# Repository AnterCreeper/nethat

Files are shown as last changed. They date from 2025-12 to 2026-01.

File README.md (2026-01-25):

# Dual Gigabit Ethernet HAT


If any questions, welcome for Issues & PRs   
如果有疑问，欢迎提交Issues或PR

**WARNING! This Project is not been fully productive tested, use at your own risk!**   
**警告！该项目未经充分的生产测试，使用需要你自己衡量**

### License

This project is licensed under the LGPL-2.1-or-later license. **DO NOT** download or clone this project until you have read and agree the LICENSE.     
该项目采用 `LGPL-2.1 以及之后版本` 授权。当你下载或克隆项目时，默认已经阅读并同意该协定。

### TODO
1. Should we add one EEPROM?

### Overview

This Project contains two `RTL8211F-CG` chips which is used to explore and demonstrate FPGA Ethernet application. This Project is compatible with [CUBE](https://github.com/AnterCreeper/CUBE) FPGA Devkit.  
该项目包含两个 `RTL8211F-CG` 芯片, 用于探索和展示基于 FPGA 的以太网应用。该项目与 [CUBE](https://github.com/AnterCreeper/CUBE) 开发工具搭配。

The PCB takes 4 layers JLC04161H-3313 Stacking, 1.6mm Thickness.
PCB 采用 4 层 JLC04161H-3313 叠层, 1.6mm 厚度。

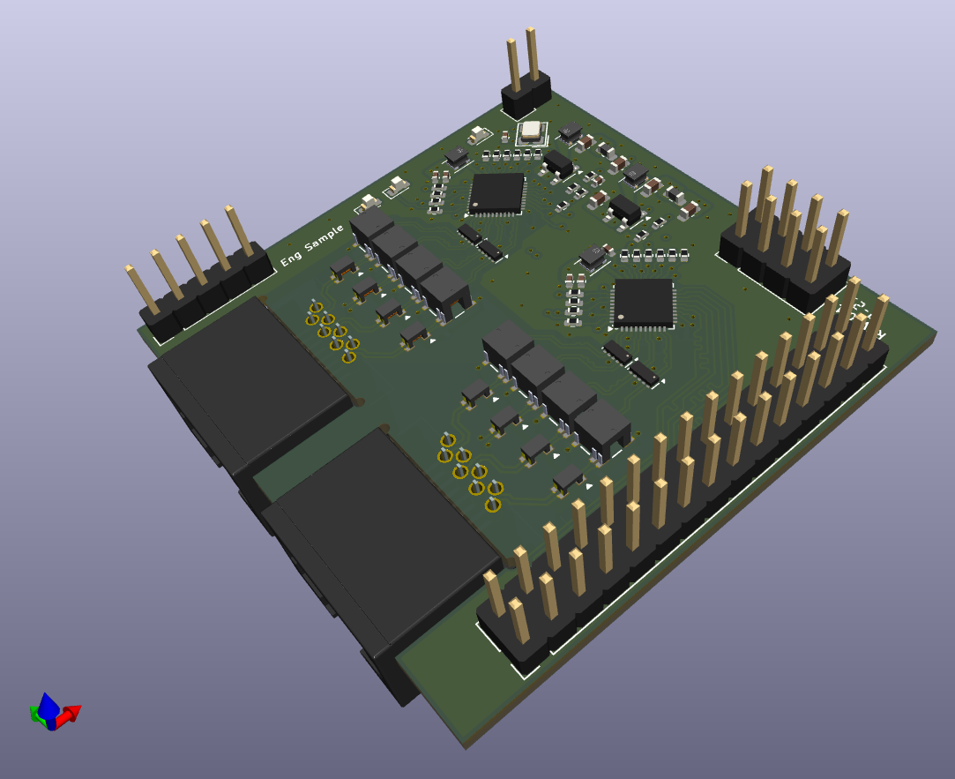
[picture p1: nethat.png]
PCB Preview Picture


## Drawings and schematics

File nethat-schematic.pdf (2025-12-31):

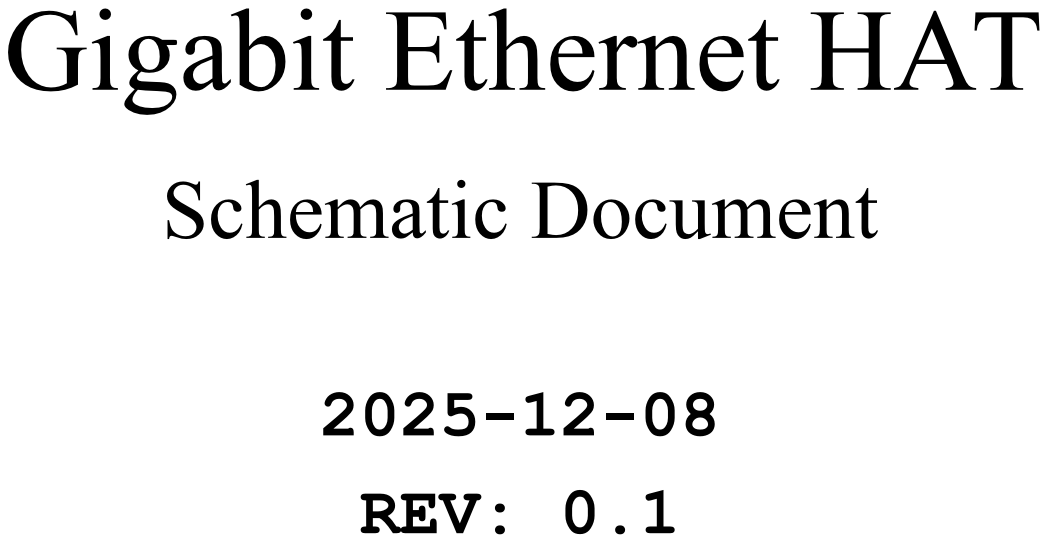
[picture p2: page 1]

Id: 1/7 Title: File: cover.kicad_sch Sheet: /COVER/ GigabitEthernetHAT
SchematicDocument

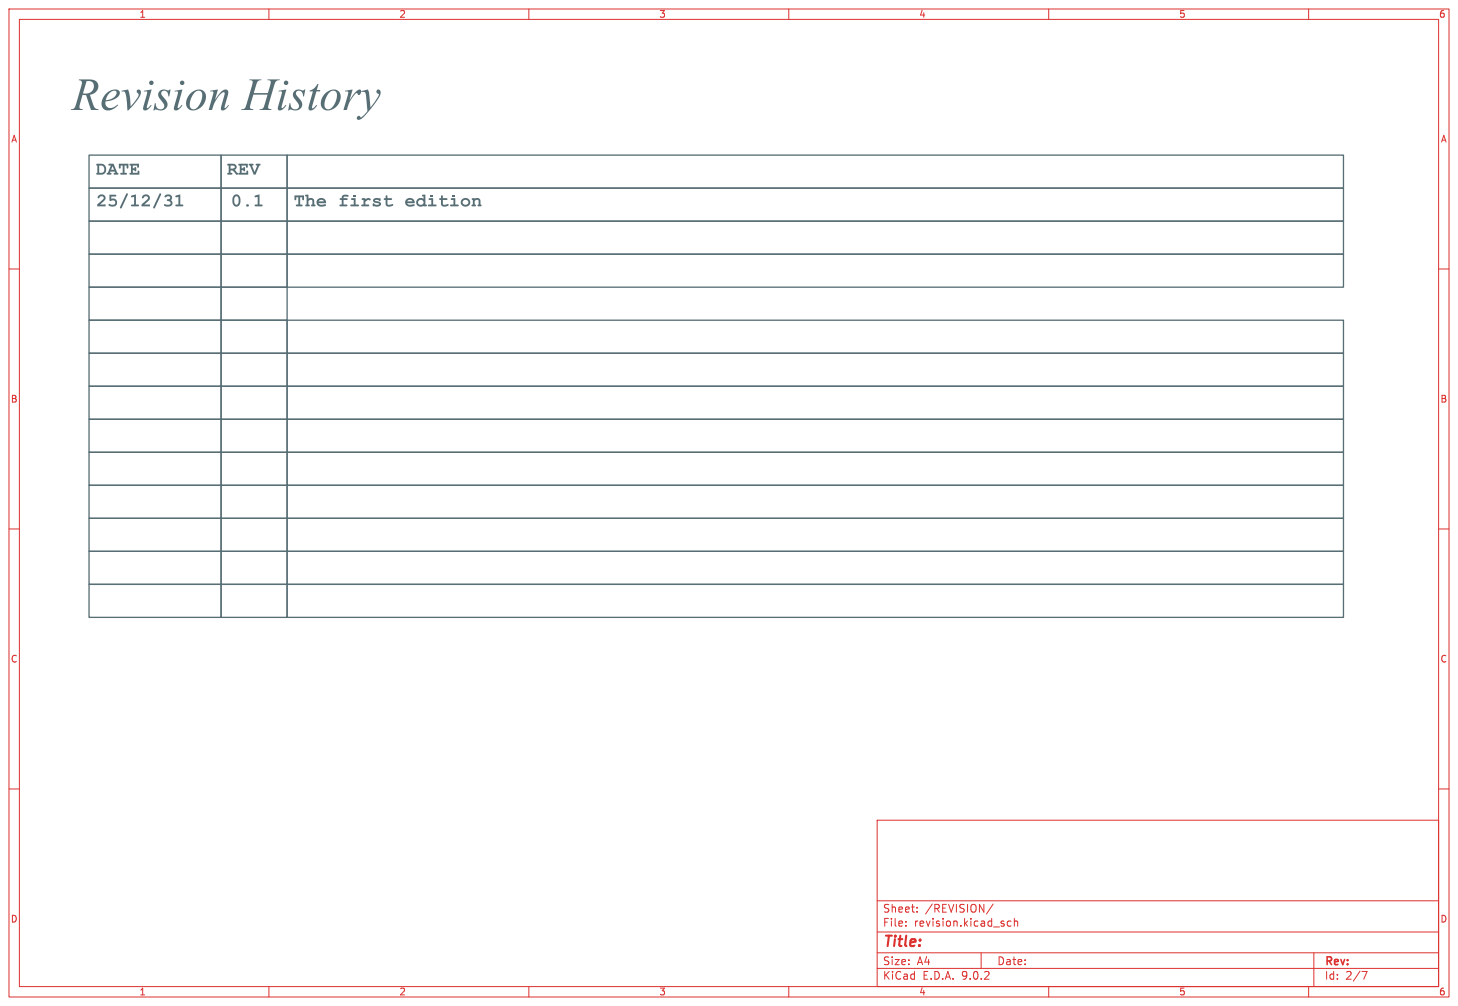
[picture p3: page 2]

Id: 2/7 Title: File: revision.kicad_sch Sheet: /REVISION/ RevisionHistory

DATE | REV
25/12/31 | 0.1 | The first edition

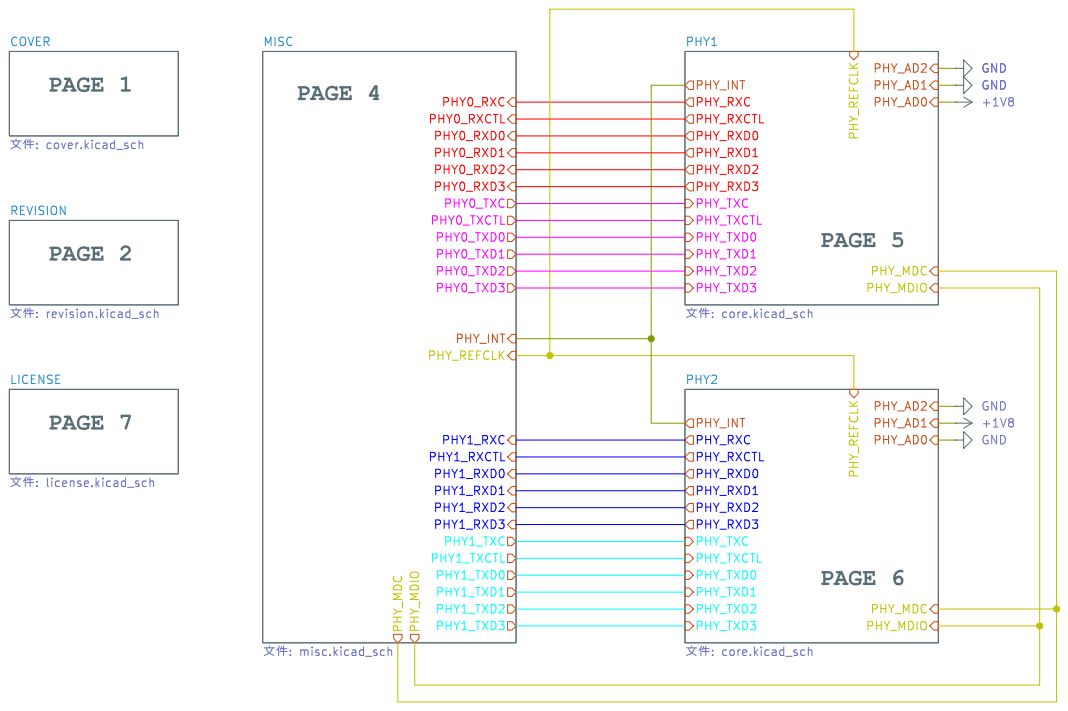
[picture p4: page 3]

þÿe‡Nö: license.kicad_sch COVER

þÿe‡Nö: cover.kicad_sch REVISION

Id: 3/7 Title: File: nethat.kicad_sch Sheet: /

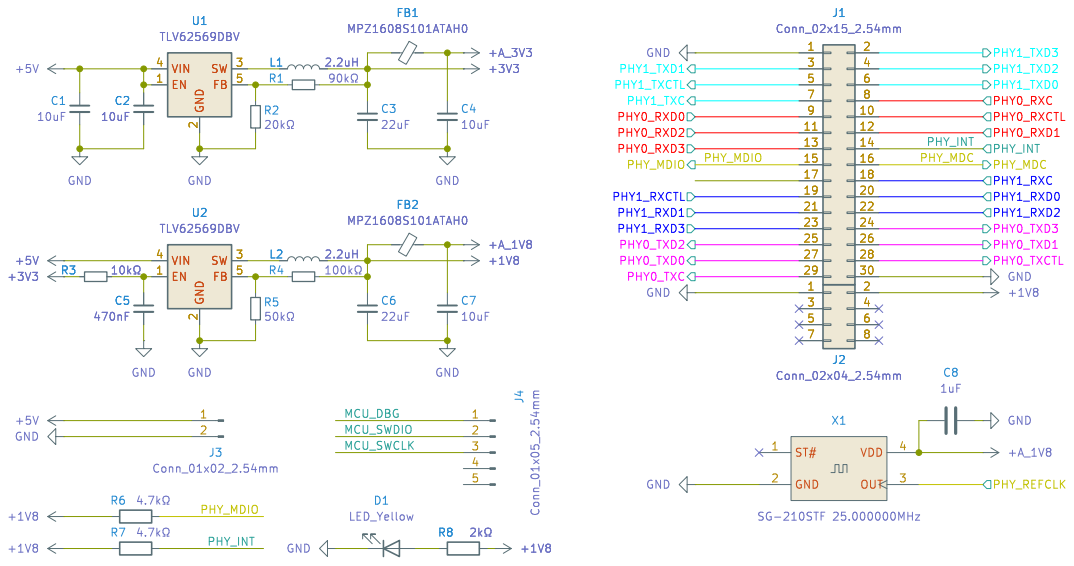
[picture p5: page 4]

2 SW 3 FB 5 U2 TLV62569DBV GND GND

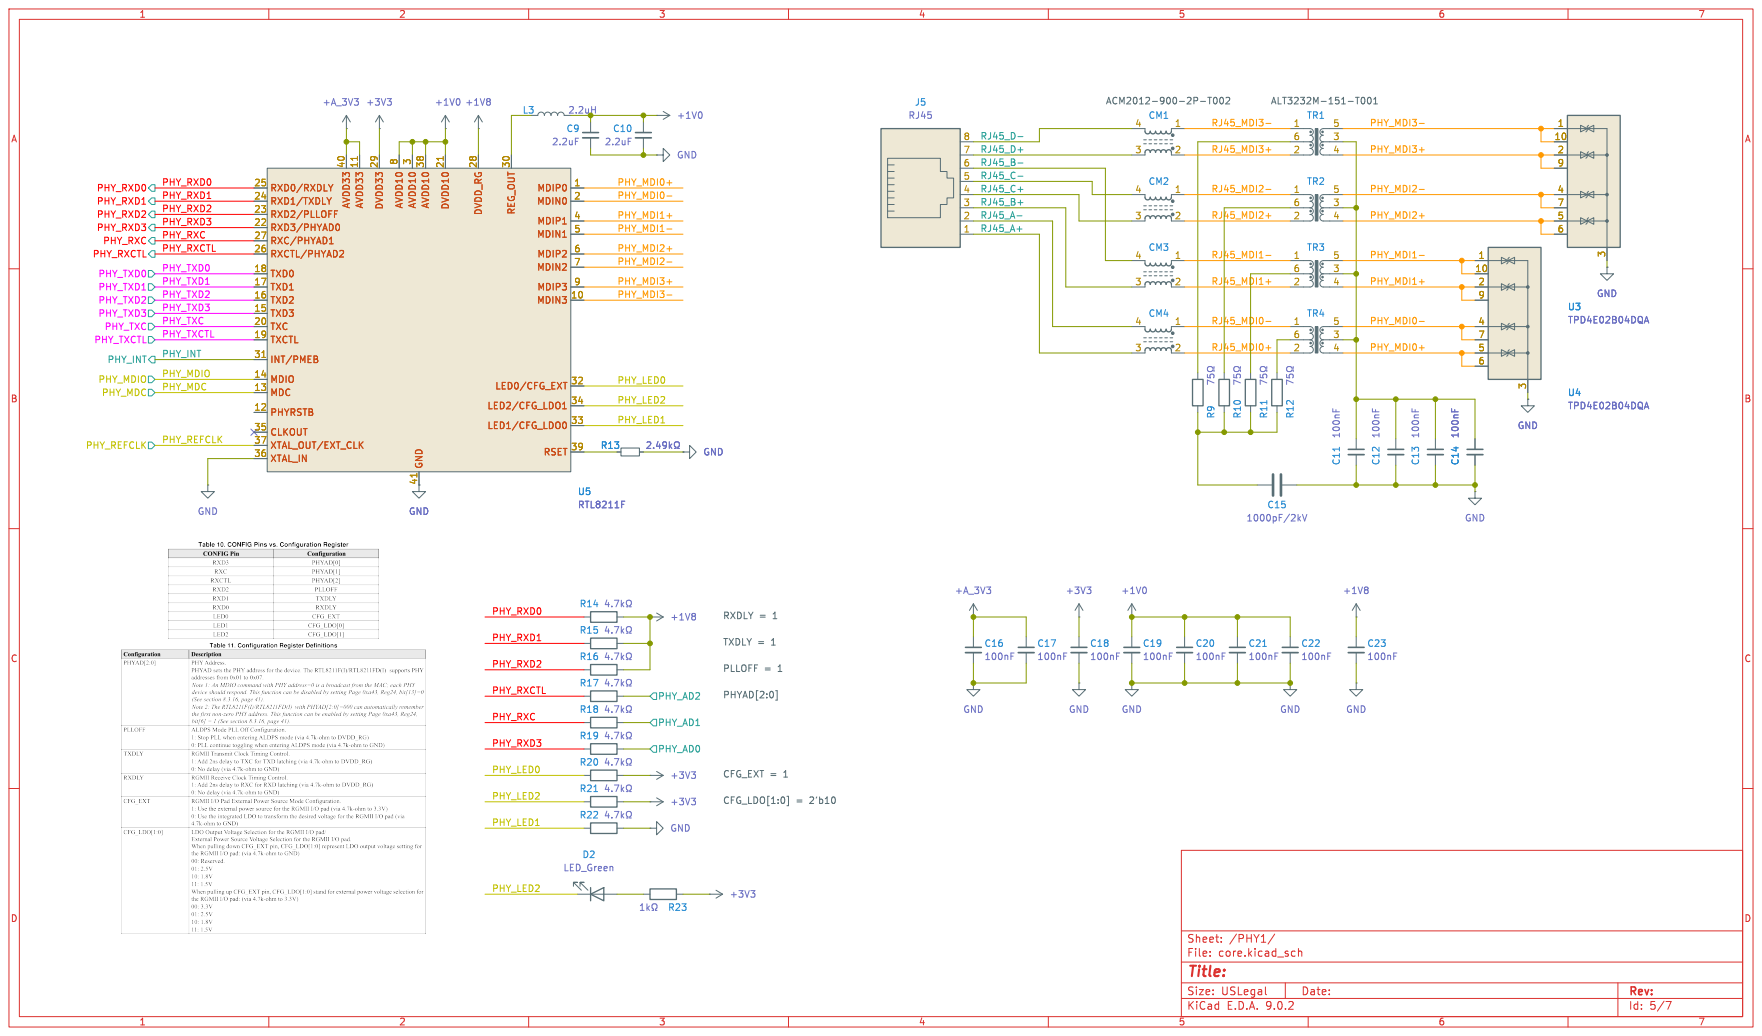
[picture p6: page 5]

Id: 5/7 Title: File: core.kicad_sch Sheet: /PHY1/

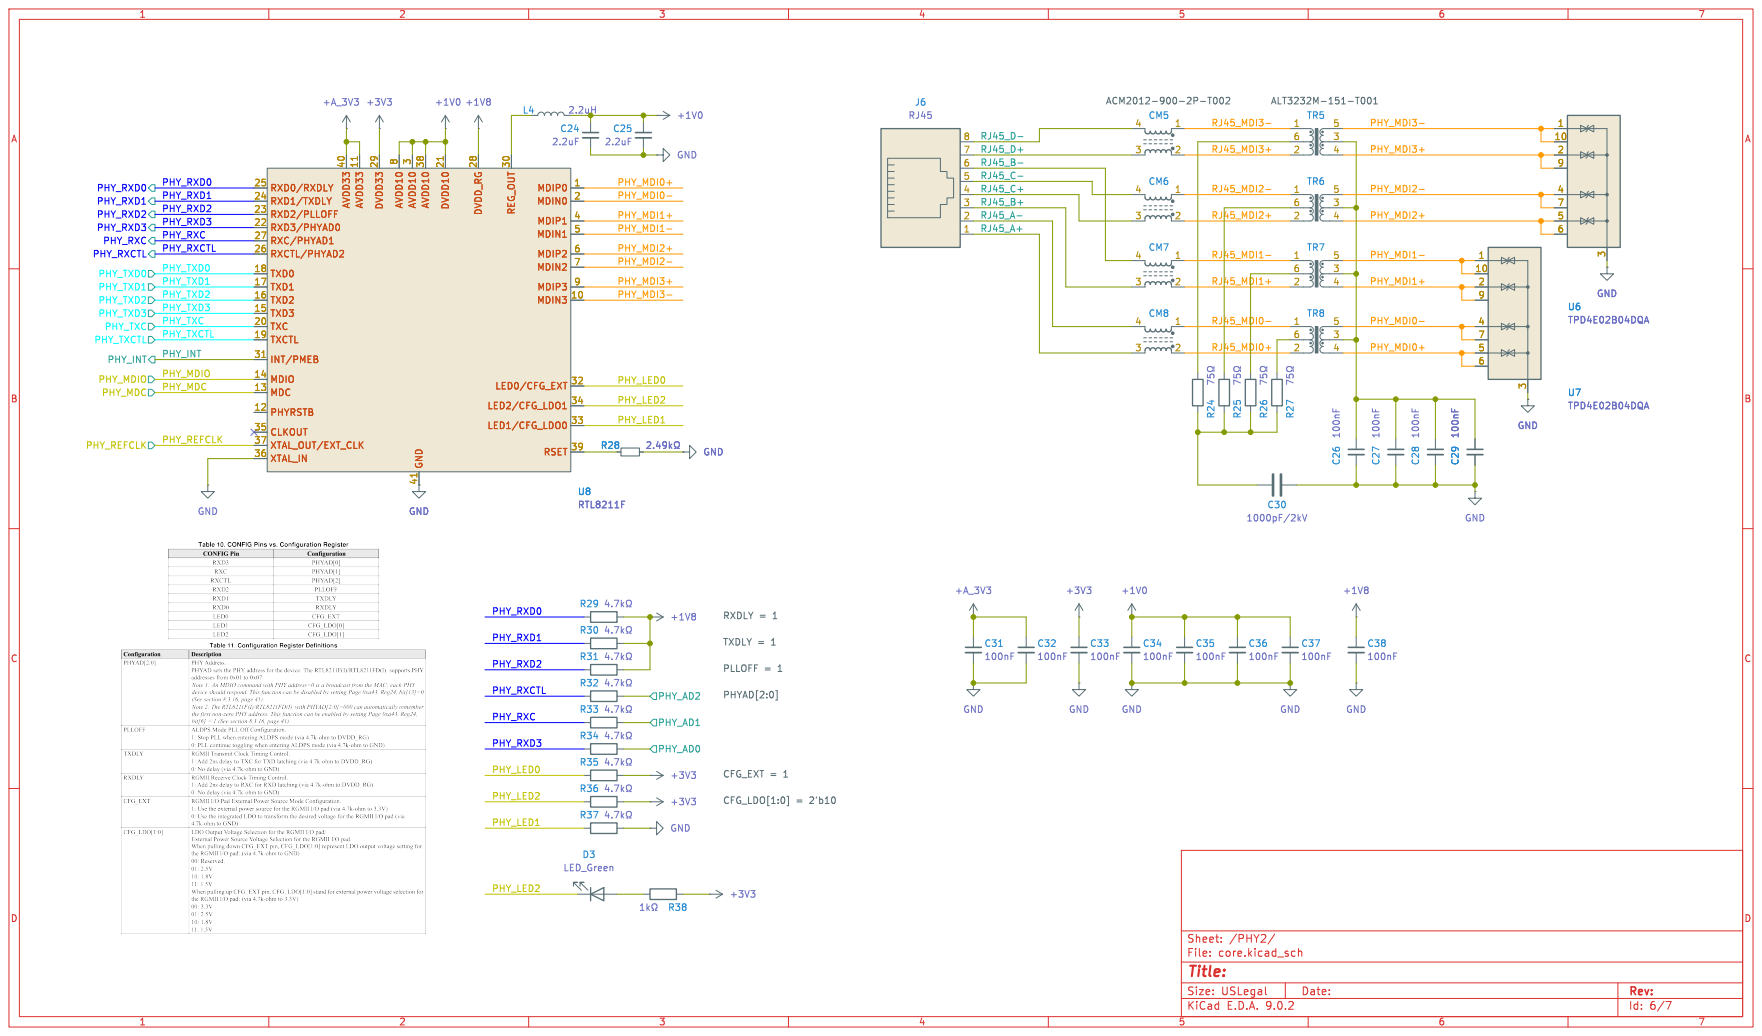
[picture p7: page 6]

Id: 6/7 Title: File: core.kicad_sch Sheet: /PHY2/

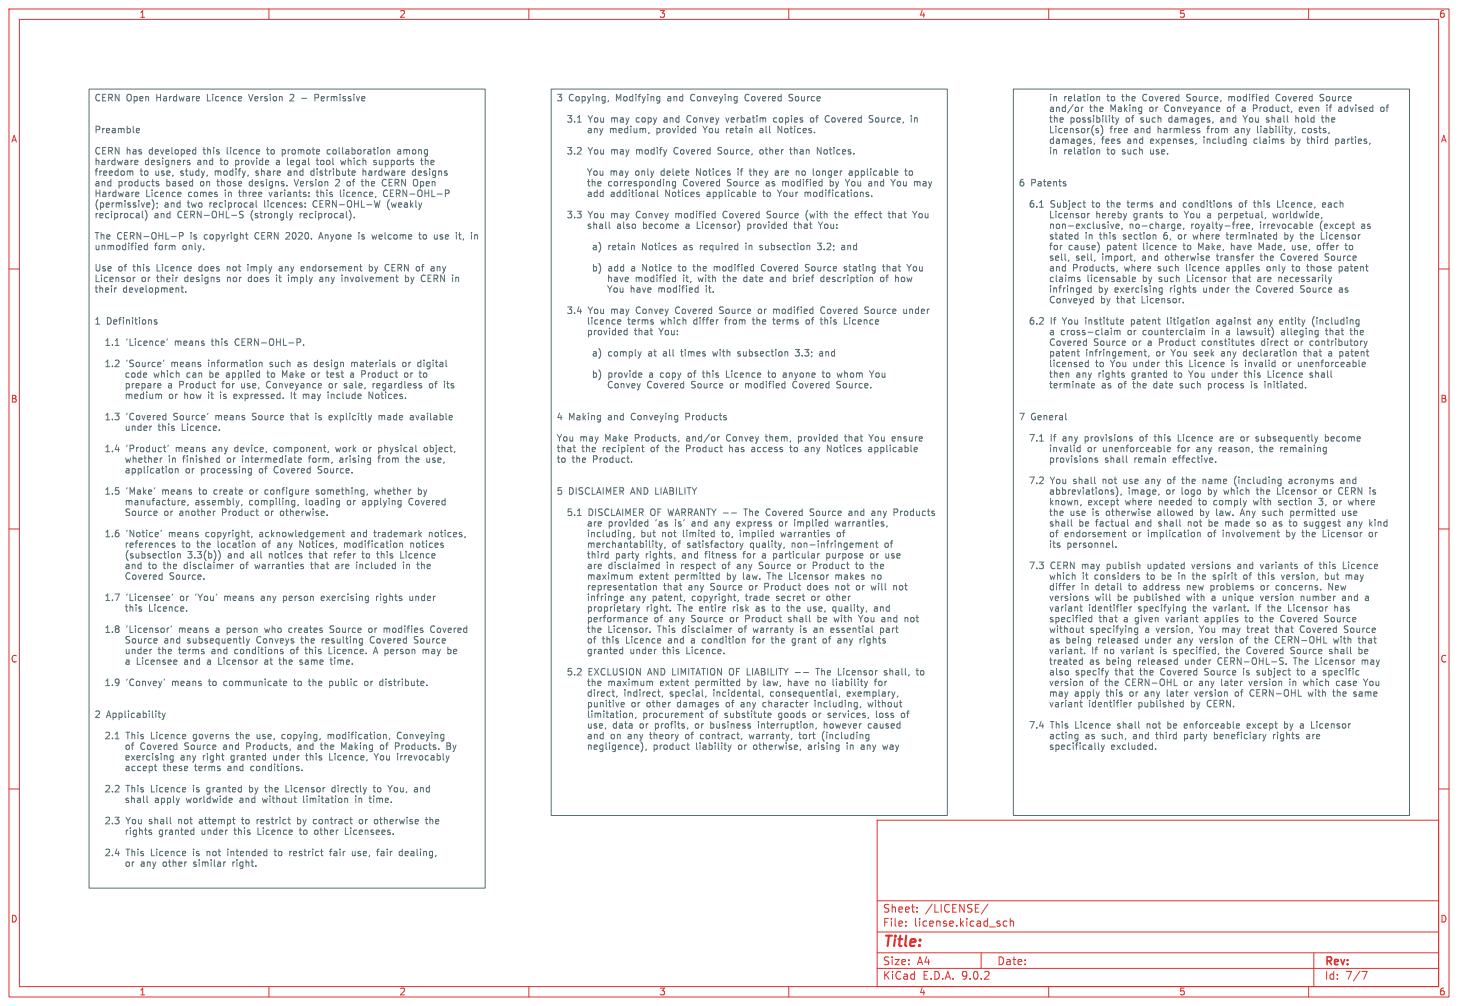
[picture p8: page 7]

for cause) patent licence to Make, have Made, use, offer to

licence terms which differ from the terms of this Licence

to the Product. 5 DISCLAIMER AND LIABILITY

known, except where needed to comply with section 3, or where

version of the CERN-OHL or any later version in which case You may apply this or any later version of CERN-OHL with the same

Id: 7/7 Title: File: license.kicad_sch Sheet: /LICENSE/

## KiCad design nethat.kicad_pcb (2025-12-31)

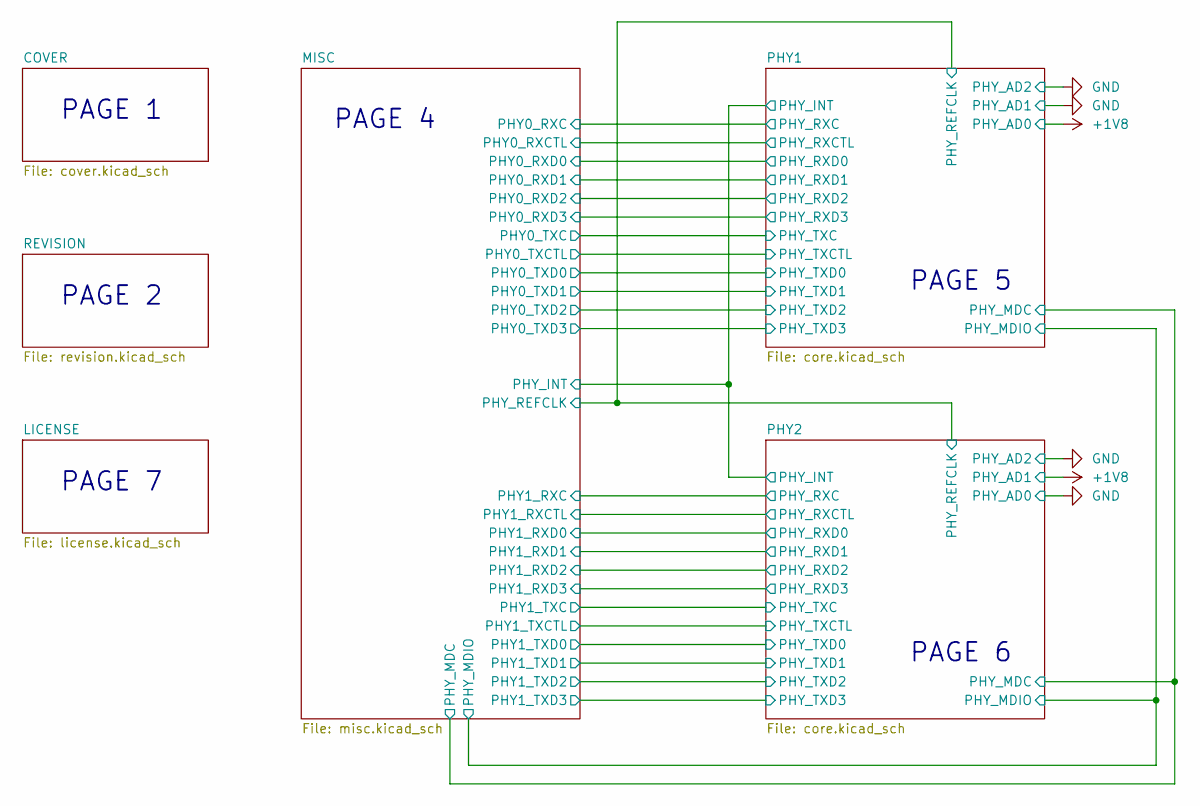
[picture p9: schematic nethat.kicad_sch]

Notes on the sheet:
PAGE 4
PAGE 1
PAGE 6
PAGE 2
PAGE 7
PAGE 5

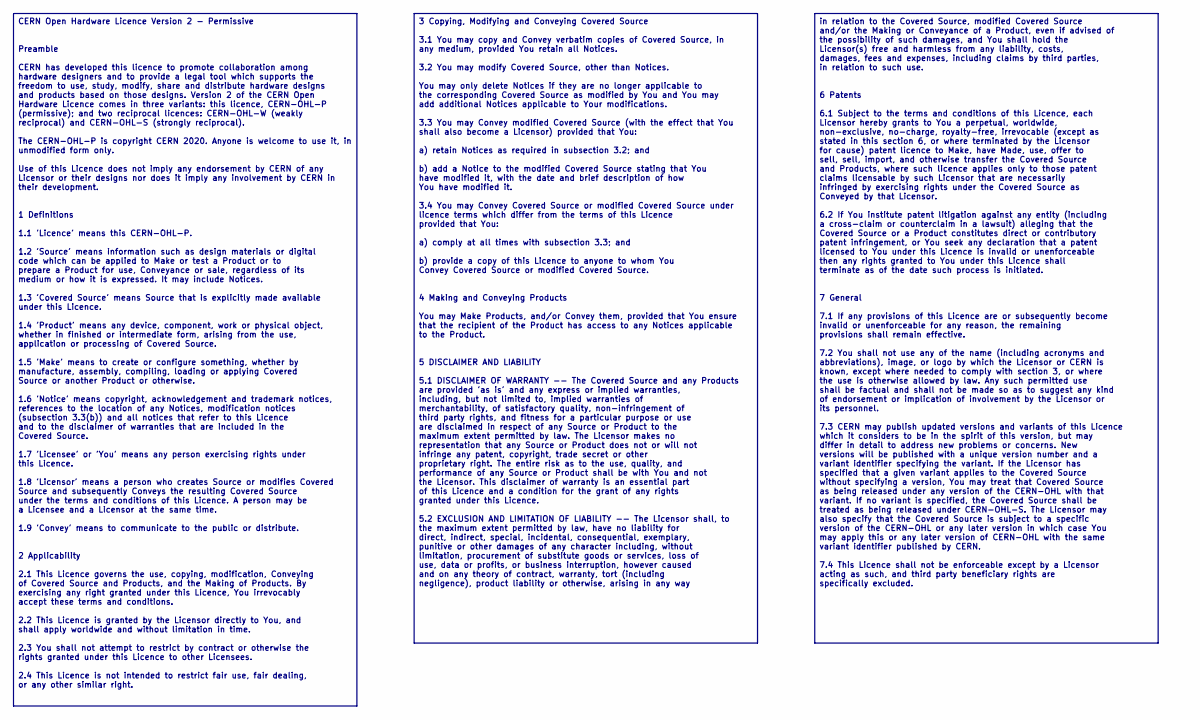
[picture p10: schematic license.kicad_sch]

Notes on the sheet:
3 Copying, Modifying and Conveying Covered Source 3.1 You may copy and Convey verbatim copies of Covered Source, in any medium, provided You retain all Notices. 3.2 You may modify Covered Source, other than Notices. You may only delete Notices if they are no longer applicable to the corresponding C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
CERN Open Hardware Licence Version 2 - Permissive Preamble CERN has developed this licence to promote collaboration among hardware designers and to provide a legal tool which supports the freedom to use, study, modify, share and distribute hardware designs and products based on those designs. Versi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
in relation to the Covered Source, modified Covered Source and/or the Making or Conveyance of a Product, even if advised of the possibility of such damages, and You shall hold the Licensor(s) free and harmless from any liability, costs, damages, fees and expenses, including claims by third parties,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

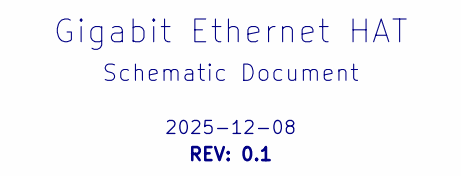
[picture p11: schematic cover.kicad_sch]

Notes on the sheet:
REV: 0.1
2025-12-08
Gigabit Ethernet HAT
Schematic Document

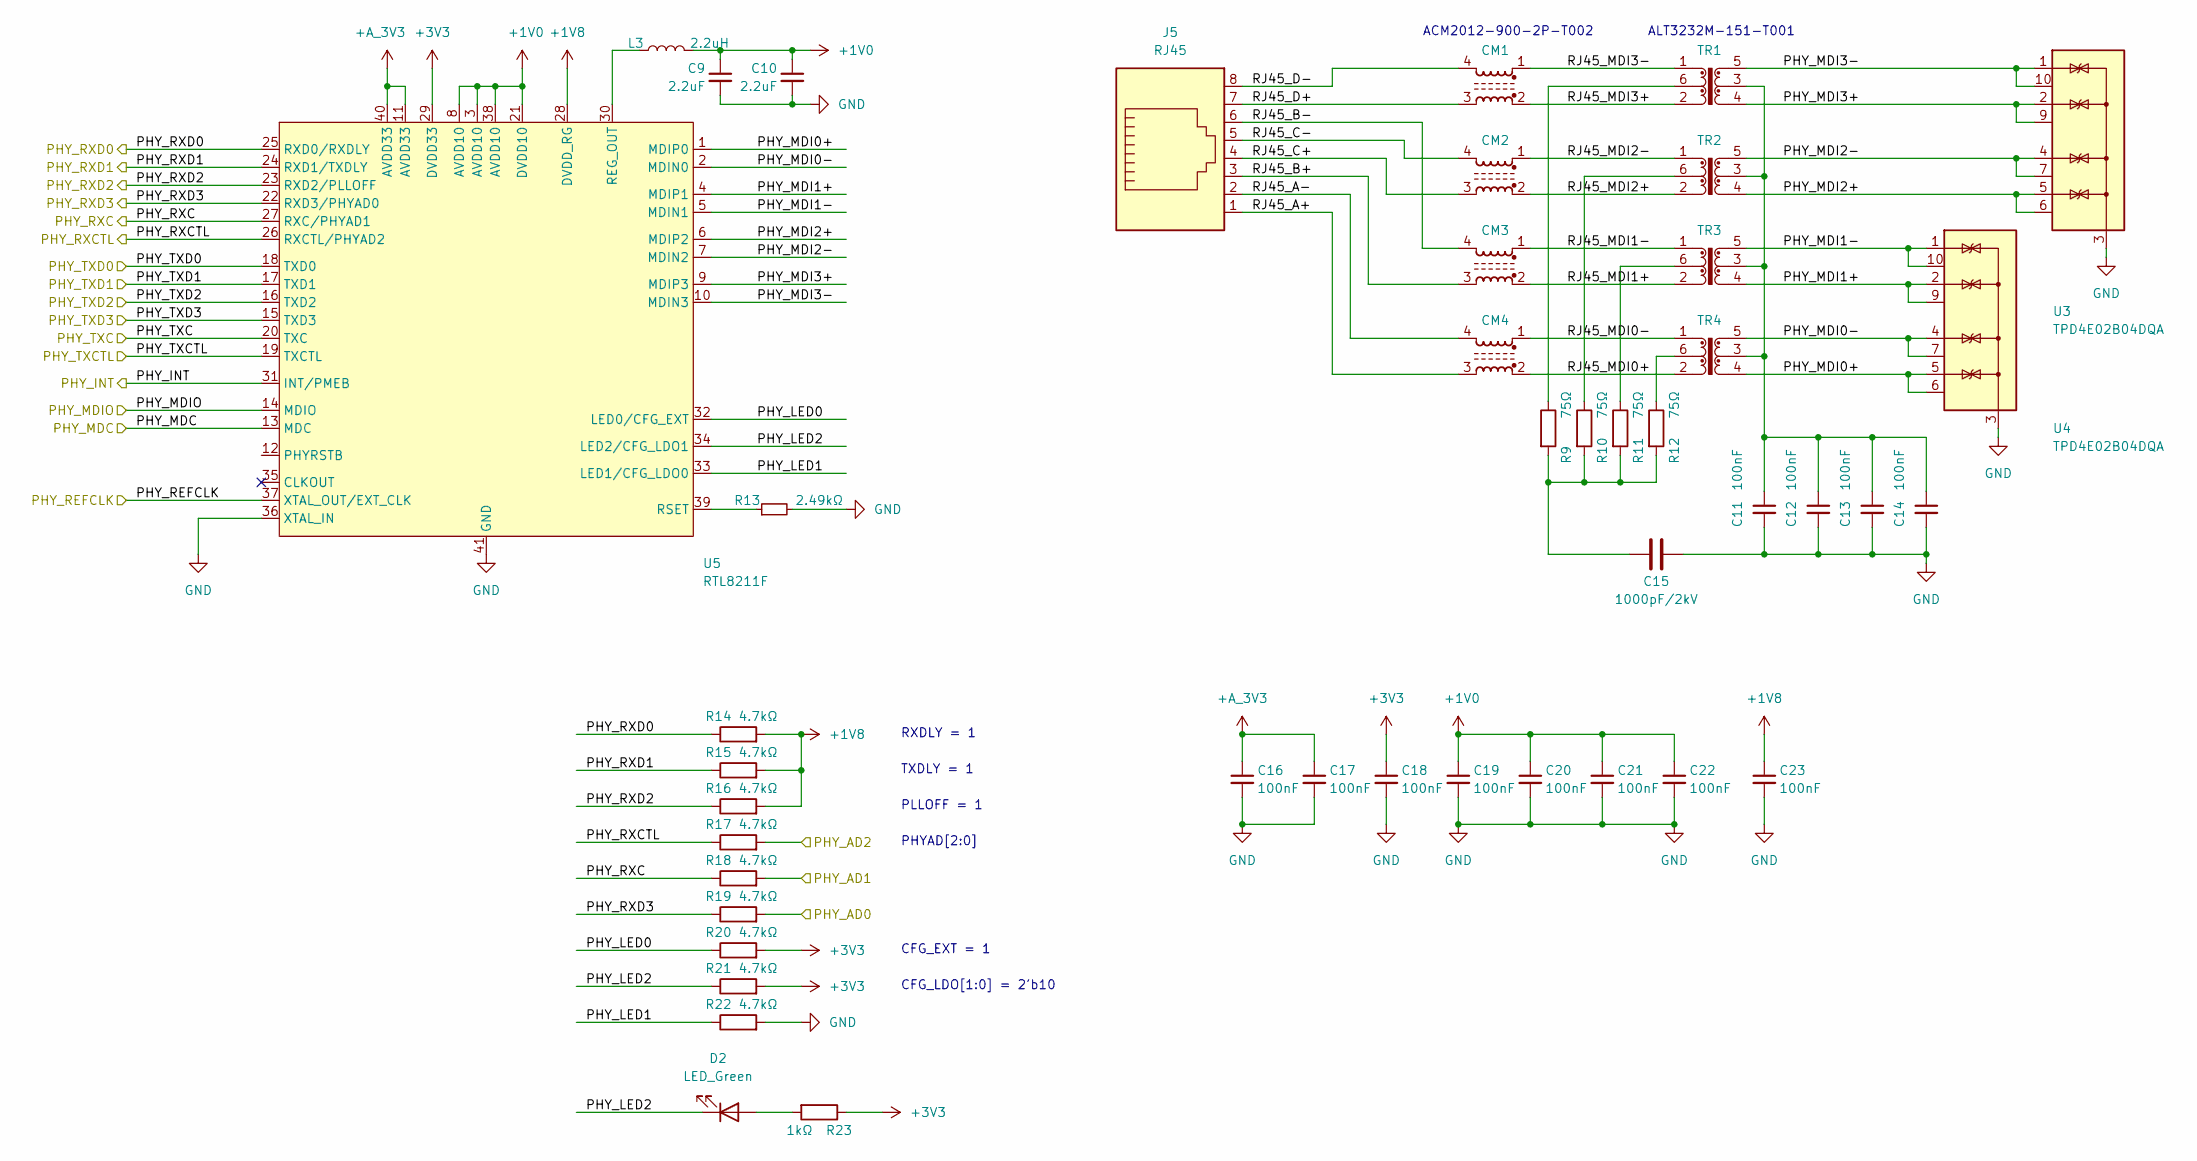
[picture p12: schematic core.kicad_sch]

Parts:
C9, C10: 2.2uF; C_0402_1005Metric
C11, C12, C13, C14, C16, C17, C18, C19, C20, C21, C22, C23: 100nF; C_0402_1005Metric
C15: 1000pF/2kV; C_1210_3225Metric
CM1, CM2, CM3, CM4: Choke_CommonMode_FerriteCore_1423; Filter_TDK_ACM2012-900-2P-T002
D2: LED_Green; LED_0603_1608Metric
J5: RJ45; RJ45_Wurth_615008150021
L3: 2.2uH; L_Murata_DFE201610P
R9, R10, R11, R12: 75Ω; R_0402_1005Metric
R13: 2.49kΩ; R_0402_1005Metric
R14, R15, R16, R17, R18, R19, R20, R21, R22: 4.7kΩ; R_0402_1005Metric
R23: 1kΩ; R_0402_1005Metric
TR1, TR2, TR3, TR4: TDK_ALT3232M_ALT4532M; Transformer_TDK_ALT3232M-151-T001
U3, U4: TPD4E02B04DQA; USON-10_2.5x1.0mm_P0.5mm
U5: RTL8211F; QFN-40-1EP_5x5mm_P0.4mm_EP3.8x3.8mm; LCSC Part C187932

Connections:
+1V0: C9.1, C10.1, C19.1, C20.1, C21.1, C22.1, L3.2, U5.3 (AVDD10), U5.8 (AVDD10), U5.21 (DVDD10), U5.38 (AVDD10); also elsewhere on the board
+1V8: C23.1, R14.2, R15.2, R16.2, R19.2, U5.28 (DVDD_RG); also elsewhere on the board
+3V3: C18.1, R20.2, R21.2, R23.1, U5.29 (DVDD33); also elsewhere on the board
+A_3V3: C16.1, C17.1, U5.11 (AVDD33), U5.40 (AVDD33); also elsewhere on the board
/MISC/PHY_INT: U5.31 (INT/PMEB); also elsewhere on the board
/MISC/PHY_MDC: U5.13 (MDC); also elsewhere on the board
/MISC/PHY_MDIO: U5.14 (MDIO); also elsewhere on the board
/PHY1/PHY_LED0: R20.1, U5.32 (LED0/CFG_EXT)
/PHY1/PHY_LED1: R22.1, U5.33 (LED1/CFG_LDO0)
/PHY1/PHY_LED2: D2.1 (K), R21.1, U5.34 (LED2/CFG_LDO1)
/PHY1/PHY_MDI0+: TR4.4, U4.5 (IO4), U4.6 (NC), U5.1 (MDIP0)
/PHY1/PHY_MDI0-: TR4.5, U4.4 (IO3), U4.7 (NC), U5.2 (MDIN0)
/PHY1/PHY_MDI1+: TR3.4, U4.2 (IO2), U4.9 (NC), U5.4 (MDIP1)
/PHY1/PHY_MDI1-: TR3.5, U4.1 (IO1), U4.10 (NC), U5.5 (MDIN1)
/PHY1/PHY_MDI2+: TR2.4, U3.5 (IO4), U3.6 (NC), U5.6 (MDIP2)
/PHY1/PHY_MDI2-: TR2.5, U3.4 (IO3), U3.7 (NC), U5.7 (MDIN2)
/PHY1/PHY_MDI3+: TR1.4, U3.2 (IO2), U3.9 (NC), U5.9 (MDIP3)
/PHY1/PHY_MDI3-: TR1.5, U3.1 (IO1), U3.10 (NC), U5.10 (MDIN3)
/PHY1/PHY_REFCLK: U5.37 (XTAL_OUT/EXT_CLK); also elsewhere on the board
/PHY1/PHY_RXC: R18.1, U5.27 (RXC/PHYAD1); also elsewhere on the board
/PHY1/PHY_RXCTL: R17.1, U5.26 (RXCTL/PHYAD2); also elsewhere on the board
/PHY1/PHY_RXD0: R14.1, U5.25 (RXD0/RXDLY); also elsewhere on the board
/PHY1/PHY_RXD1: R15.1, U5.24 (RXD1/TXDLY); also elsewhere on the board
/PHY1/PHY_RXD2: R16.1, U5.23 (RXD2/PLLOFF); also elsewhere on the board
/PHY1/PHY_RXD3: R19.1, U5.22 (RXD3/PHYAD0); also elsewhere on the board
/PHY1/PHY_TXC: U5.20 (TXC); also elsewhere on the board
/PHY1/PHY_TXCTL: U5.19 (TXCTL); also elsewhere on the board
/PHY1/PHY_TXD0: U5.18 (TXD0); also elsewhere on the board
/PHY1/PHY_TXD1: U5.17 (TXD1); also elsewhere on the board
/PHY1/PHY_TXD2: U5.16 (TXD2); also elsewhere on the board
/PHY1/PHY_TXD3: U5.15 (TXD3); also elsewhere on the board
/PHY1/RJ45_A+: CM4.3, J5.1
/PHY1/RJ45_A-: CM4.4, J5.2
/PHY1/RJ45_B+: CM3.3, J5.3
/PHY1/RJ45_B-: CM3.4, J5.6
/PHY1/RJ45_C+: CM2.3, J5.4
/PHY1/RJ45_C-: CM2.4, J5.5
/PHY1/RJ45_D+: CM1.3, J5.7
/PHY1/RJ45_D-: CM1.4, J5.8
/PHY1/RJ45_MDI0+: CM4.2, TR4.2
/PHY1/RJ45_MDI0-: CM4.1, TR4.1
/PHY1/RJ45_MDI1+: CM3.2, TR3.2
/PHY1/RJ45_MDI1-: CM3.1, TR3.1
/PHY1/RJ45_MDI2+: CM2.2, TR2.2
/PHY1/RJ45_MDI2-: CM2.1, TR2.1
/PHY1/RJ45_MDI3+: CM1.2, TR1.2
/PHY1/RJ45_MDI3-: CM1.1, TR1.1
GND: C9.2, C10.2, C11.2, C12.2, C13.2, C14.2, C15.2, C16.2, C17.2, C18.2, C19.2, C20.2, C21.2, C22.2, C23.2, R13.2, R17.2, R18.2, R22.2, U3.3 (G), U3.8 (G), U4.3 (G), U4.8 (G), U5.36 (XTAL_IN), U5.41 (GND); also elsewhere on the board
unnamed: C11.1, C12.1, C13.1, C14.1, TR1.3, TR2.3, TR3.3, TR4.3
unnamed: C15.1, R9.2, R10.2, R11.2, R12.2
unnamed: D2.2 (A), R23.2
unnamed: R9.1, TR1.6
unnamed: R10.1, TR2.6
unnamed: R11.1, TR3.6
unnamed: R12.1, TR4.6
unnamed: L3.1, U5.30 (REG_OUT)
unnamed: R13.1, U5.39 (RSET)

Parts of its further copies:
C24, C25: 2.2uF; C_0402_1005Metric
C26, C27, C28, C29, C31, C32, C33, C34, C35, C36, C37, C38: 100nF; C_0402_1005Metric
C30: 1000pF/2kV; C_1210_3225Metric
CM5, CM6, CM7, CM8: Choke_CommonMode_FerriteCore_1423; Filter_TDK_ACM2012-900-2P-T002
D3: LED_Green; LED_0603_1608Metric
J6: RJ45; RJ45_Wurth_615008150021
L4: 2.2uH; L_Murata_DFE201610P
R24, R25, R26, R27: 75Ω; R_0402_1005Metric
R28: 2.49kΩ; R_0402_1005Metric
R29, R30, R31, R32, R33, R34, R35, R36, R37: 4.7kΩ; R_0402_1005Metric
R38: 1kΩ; R_0402_1005Metric
TR5, TR6, TR7, TR8: TDK_ALT3232M_ALT4532M; Transformer_TDK_ALT3232M-151-T001
U6, U7: TPD4E02B04DQA; USON-10_2.5x1.0mm_P0.5mm
U8: RTL8211F; QFN-40-1EP_5x5mm_P0.4mm_EP3.8x3.8mm; LCSC Part C187932

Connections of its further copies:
+1V0: C24.1, C25.1, C34.1, C35.1, C36.1, C37.1, L4.2, U8.3 (AVDD10), U8.8 (AVDD10), U8.21 (DVDD10), U8.38 (AVDD10); also elsewhere on the board
+1V8: C38.1, R29.2, R30.2, R31.2, R33.2, U8.28 (DVDD_RG); also elsewhere on the board
+3V3: C33.1, R35.2, R36.2, R38.1, U8.29 (DVDD33); also elsewhere on the board
+A_3V3: C31.1, C32.1, U8.11 (AVDD33), U8.40 (AVDD33); also elsewhere on the board
/MISC/PHY_INT: U8.31 (INT/PMEB); also elsewhere on the board
/MISC/PHY_MDC: U8.13 (MDC); also elsewhere on the board
/MISC/PHY_MDIO: U8.14 (MDIO); also elsewhere on the board
/PHY1/PHY_REFCLK: U8.37 (XTAL_OUT/EXT_CLK); also elsewhere on the board
/PHY2/PHY_LED0: R35.1, U8.32 (LED0/CFG_EXT)
/PHY2/PHY_LED1: R37.1, U8.33 (LED1/CFG_LDO0)
/PHY2/PHY_LED2: D3.1 (K), R36.1, U8.34 (LED2/CFG_LDO1)
/PHY2/PHY_MDI0+: TR8.4, U7.5 (IO4), U7.6 (NC), U8.1 (MDIP0)
/PHY2/PHY_MDI0-: TR8.5, U7.4 (IO3), U7.7 (NC), U8.2 (MDIN0)
/PHY2/PHY_MDI1+: TR7.4, U7.2 (IO2), U7.9 (NC), U8.4 (MDIP1)
/PHY2/PHY_MDI1-: TR7.5, U7.1 (IO1), U7.10 (NC), U8.5 (MDIN1)
/PHY2/PHY_MDI2+: TR6.4, U6.5 (IO4), U6.6 (NC), U8.6 (MDIP2)
/PHY2/PHY_MDI2-: TR6.5, U6.4 (IO3), U6.7 (NC), U8.7 (MDIN2)
/PHY2/PHY_MDI3+: TR5.4, U6.2 (IO2), U6.9 (NC), U8.9 (MDIP3)
/PHY2/PHY_MDI3-: TR5.5, U6.1 (IO1), U6.10 (NC), U8.10 (MDIN3)
/PHY2/PHY_RXC: R33.1, U8.27 (RXC/PHYAD1); also elsewhere on the board
/PHY2/PHY_RXCTL: R32.1, U8.26 (RXCTL/PHYAD2); also elsewhere on the board
/PHY2/PHY_RXD0: R29.1, U8.25 (RXD0/RXDLY); also elsewhere on the board
/PHY2/PHY_RXD1: R30.1, U8.24 (RXD1/TXDLY); also elsewhere on the board
/PHY2/PHY_RXD2: R31.1, U8.23 (RXD2/PLLOFF); also elsewhere on the board
/PHY2/PHY_RXD3: R34.1, U8.22 (RXD3/PHYAD0); also elsewhere on the board
/PHY2/PHY_TXC: U8.20 (TXC); also elsewhere on the board
/PHY2/PHY_TXCTL: U8.19 (TXCTL); also elsewhere on the board
/PHY2/PHY_TXD0: U8.18 (TXD0); also elsewhere on the board
/PHY2/PHY_TXD1: U8.17 (TXD1); also elsewhere on the board
/PHY2/PHY_TXD2: U8.16 (TXD2); also elsewhere on the board
/PHY2/PHY_TXD3: U8.15 (TXD3); also elsewhere on the board
/PHY2/RJ45_A+: CM8.3, J6.1
/PHY2/RJ45_A-: CM8.4, J6.2
/PHY2/RJ45_B+: CM7.3, J6.3
/PHY2/RJ45_B-: CM7.4, J6.6
/PHY2/RJ45_C+: CM6.3, J6.4
/PHY2/RJ45_C-: CM6.4, J6.5
/PHY2/RJ45_D+: CM5.3, J6.7
/PHY2/RJ45_D-: CM5.4, J6.8
/PHY2/RJ45_MDI0+: CM8.2, TR8.2
/PHY2/RJ45_MDI0-: CM8.1, TR8.1
/PHY2/RJ45_MDI1+: CM7.2, TR7.2
/PHY2/RJ45_MDI1-: CM7.1, TR7.1
/PHY2/RJ45_MDI2+: CM6.2, TR6.2
/PHY2/RJ45_MDI2-: CM6.1, TR6.1
/PHY2/RJ45_MDI3+: CM5.2, TR5.2
/PHY2/RJ45_MDI3-: CM5.1, TR5.1
GND: C24.2, C25.2, C26.2, C27.2, C28.2, C29.2, C30.2, C31.2, C32.2, C33.2, C34.2, C35.2, C36.2, C37.2, C38.2, R28.2, R32.2, R34.2, R37.2, U6.3 (G), U6.8 (G), U7.3 (G), U7.8 (G), U8.36 (XTAL_IN), U8.41 (GND); also elsewhere on the board
unnamed: C26.1, C27.1, C28.1, C29.1, TR5.3, TR6.3, TR7.3, TR8.3
unnamed: C30.1, R24.2, R25.2, R26.2, R27.2
unnamed: D3.2 (A), R38.2
unnamed: R24.1, TR5.6
unnamed: R25.1, TR6.6
unnamed: R26.1, TR7.6
unnamed: R27.1, TR8.6
unnamed: L4.1, U8.30 (REG_OUT)
unnamed: R28.1, U8.39 (RSET)

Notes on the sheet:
ACM2012-900-2P-T002
PHYAD[2:0]
CFG_LDO[1:0] = 2'b10
CFG_EXT = 1
RXDLY = 1
PLLOFF = 1
ALT3232M-151-T001
TXDLY = 1

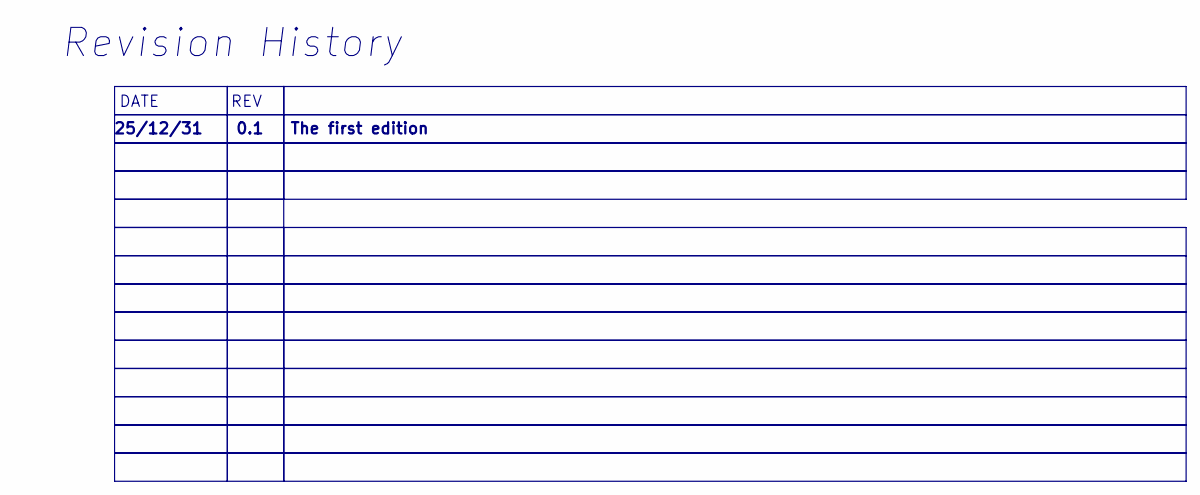
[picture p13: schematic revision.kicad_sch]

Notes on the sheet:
The first edition
Revision History
REV
25/12/31
0.1
DATE

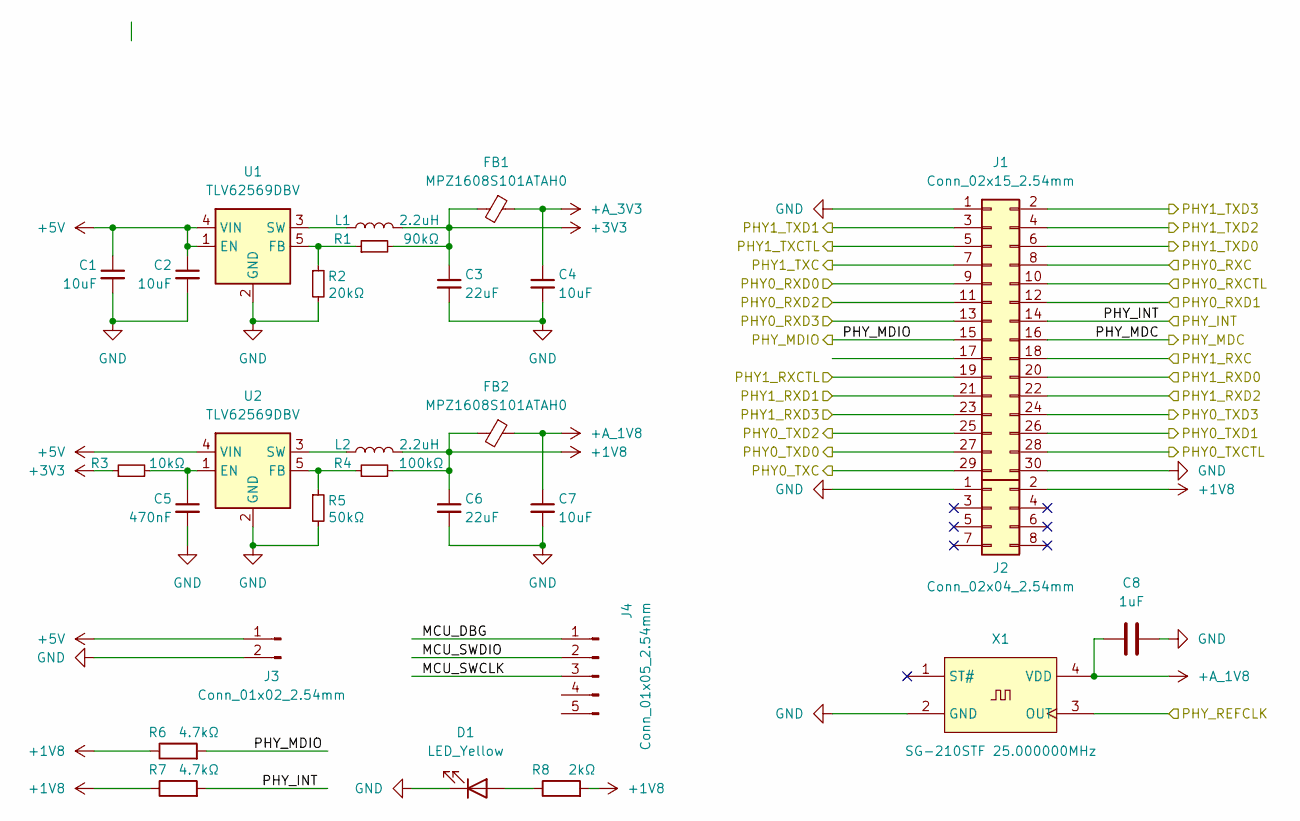
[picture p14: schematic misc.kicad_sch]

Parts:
C1, C2, C4, C7: 10uF; C_0603_1608Metric
C3, C6: 22uF; C_0603_1608Metric
C5: 470nF; C_0402_1005Metric
C8: 1uF; C_0402_1005Metric
D1: LED_Yellow; LED_0603_1608Metric
FB1, FB2: MPZ1608S101ATAH0; L_0603_1608Metric
J1: Conn_02x15_2.54mm; PinHeader_2x15_P2.54mm_Vertical
J2: Conn_02x04_2.54mm; PinHeader_2x04_P2.54mm_Vertical
J3: Conn_01x02_2.54mm; PinHeader_1x02_P2.54mm_Vertical
J4: Conn_01x05_2.54mm; PinHeader_1x05_P2.54mm_Vertical
L1, L2: 2.2uH; L_Murata_DFE201610P
R1: 90kΩ; R_0402_1005Metric
R2: 20kΩ; R_0402_1005Metric
R3: 10kΩ; R_0402_1005Metric
R4: 100kΩ; R_0402_1005Metric
R5: 50kΩ; R_0402_1005Metric
R6, R7: 4.7kΩ; R_0402_1005Metric
R8: 2kΩ; R_0402_1005Metric
U1, U2: TLV62569DBV; SOT-23-5
X1: SG-210STF 25.000000MHz; Oscillator_SMD_SeikoEpson_SG210-4Pin_2.5x2.0mm

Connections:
+1V8: C6.1, FB2.2, J2.2, L2.2, R4.2, R6.1, R7.1, R8.2; also elsewhere on the board
+3V3: C3.1, FB1.2, L1.2, R1.2, R3.1; also elsewhere on the board
+5V: C1.1, C2.1, J3.1, U1.1 (EN), U1.4 (VIN), U2.4 (VIN)
+A_1V8: C7.1, C8.1, FB2.1, X1.4 (VDD)
+A_3V3: C4.1, FB1.1; also elsewhere on the board
/MISC/MCU_DBG: J4.1
/MISC/MCU_SWCLK: J4.3
/MISC/MCU_SWDIO: J4.2
/MISC/PHY_INT: J1.14, R7.2; also elsewhere on the board
/MISC/PHY_MDC: J1.16; also elsewhere on the board
/MISC/PHY_MDIO: J1.15, R6.2; also elsewhere on the board
/PHY1/PHY_REFCLK: X1.3 (OUT); also elsewhere on the board
/PHY1/PHY_RXC: J1.8; also elsewhere on the board
/PHY1/PHY_RXCTL: J1.10; also elsewhere on the board
/PHY1/PHY_RXD0: J1.9; also elsewhere on the board
/PHY1/PHY_RXD1: J1.12; also elsewhere on the board
/PHY1/PHY_RXD2: J1.11; also elsewhere on the board
/PHY1/PHY_RXD3: J1.13; also elsewhere on the board
/PHY1/PHY_TXC: J1.29; also elsewhere on the board
/PHY1/PHY_TXCTL: J1.28; also elsewhere on the board
/PHY1/PHY_TXD0: J1.27; also elsewhere on the board
/PHY1/PHY_TXD1: J1.26; also elsewhere on the board
/PHY1/PHY_TXD2: J1.25; also elsewhere on the board
/PHY1/PHY_TXD3: J1.24; also elsewhere on the board
/PHY2/PHY_RXC: J1.18; also elsewhere on the board
/PHY2/PHY_RXCTL: J1.19; also elsewhere on the board
/PHY2/PHY_RXD0: J1.20; also elsewhere on the board
/PHY2/PHY_RXD1: J1.21; also elsewhere on the board
/PHY2/PHY_RXD2: J1.22; also elsewhere on the board
/PHY2/PHY_RXD3: J1.23; also elsewhere on the board
/PHY2/PHY_TXC: J1.7; also elsewhere on the board
/PHY2/PHY_TXCTL: J1.5; also elsewhere on the board
/PHY2/PHY_TXD0: J1.6; also elsewhere on the board
/PHY2/PHY_TXD1: J1.3; also elsewhere on the board
/PHY2/PHY_TXD2: J1.4; also elsewhere on the board
/PHY2/PHY_TXD3: J1.2; also elsewhere on the board
GND: C1.2, C2.2, C3.2, C4.2, C5.2, C6.2, C7.2, C8.2, D1.1 (K), J1.1, J1.30, J2.1, J3.2, R2.2, R5.2, U1.2 (GND), U2.2 (GND), X1.2 (GND); also elsewhere on the board
unnamed: D1.2 (A), R8.1
unnamed: R1.1, R2.1, U1.5 (FB)
unnamed: L1.1, U1.3 (SW)
unnamed: C5.1, R3.2, U2.1 (EN)
unnamed: R4.1, R5.1, U2.5 (FB)
unnamed: L2.1, U2.3 (SW)

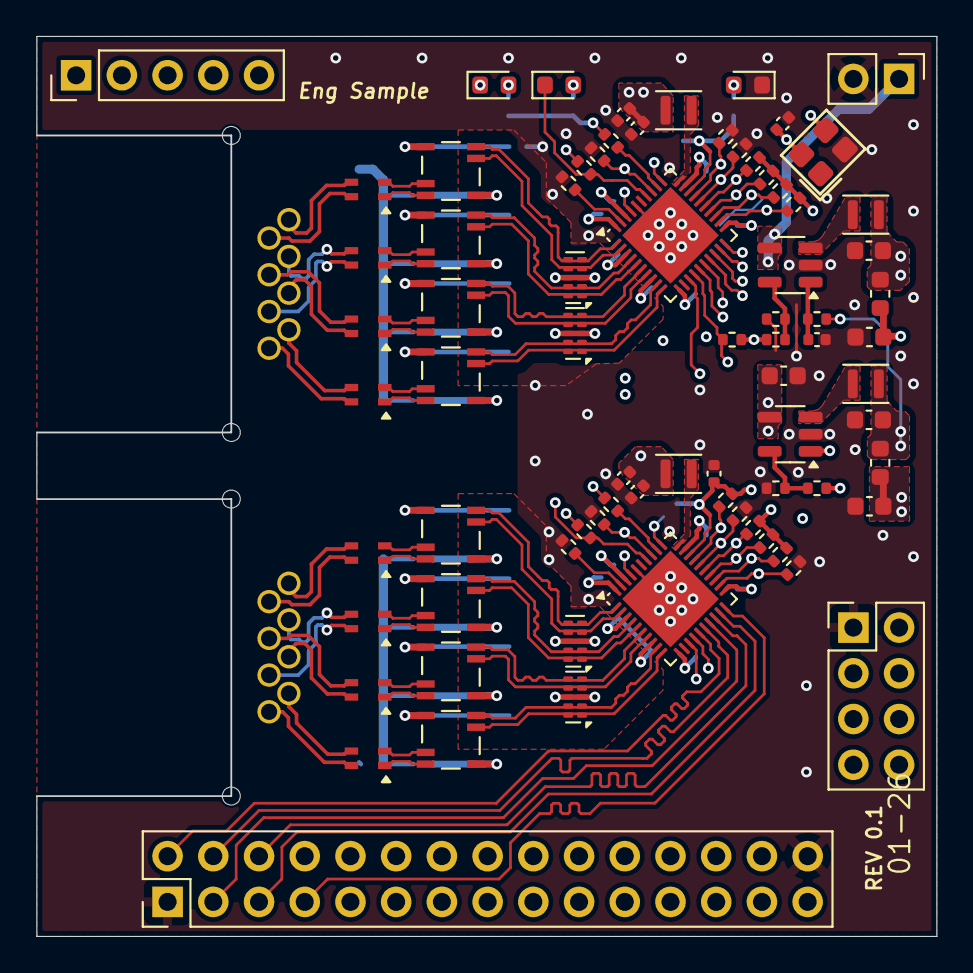
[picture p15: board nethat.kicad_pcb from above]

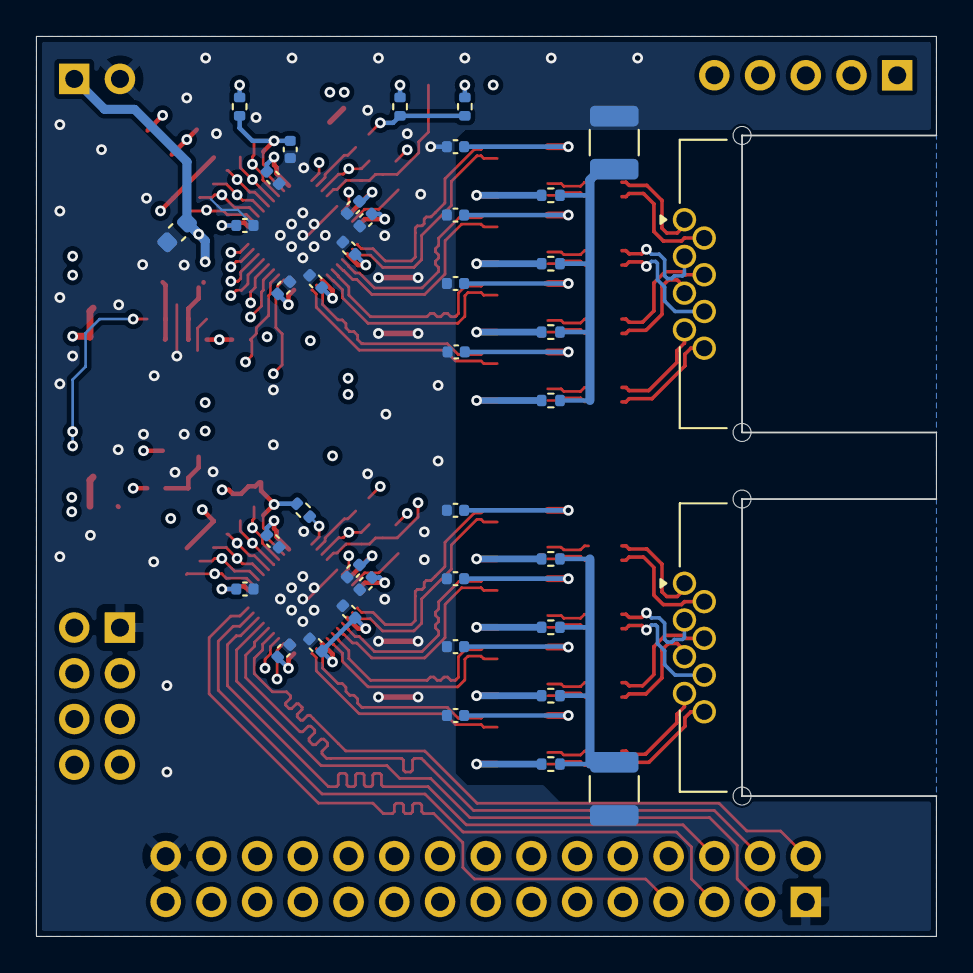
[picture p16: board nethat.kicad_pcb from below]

Board: 4 copper layers, 50.0 x 50.0 mm, 116 parts (40 on the bottom side), 113 nets.

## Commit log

2025-12-20 init project.
    [core.kicad_sch, cover.kicad_sch, license.kicad_sch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]
2025-12-22 update schematic.
    [core.kicad_sch, misc.kicad_sch, nethat.kicad_sch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]
2025-12-23 finish schematic.
    [core.kicad_sch, misc.kicad_sch, nethat.kicad_pcb]
2025-12-23 update schematic pdf and step models.
    [cover.kicad_sch]
2025-12-30 first version release.
    [core.kicad_sch, misc.kicad_sch, nethat.kicad_pcb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]
2025-12-31 first release v0.1
    [core.kicad_sch, misc.kicad_sch, nethat.kicad_pcb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]
2025-12-31 tiny fixup.
    [nethat.kicad_pcb]

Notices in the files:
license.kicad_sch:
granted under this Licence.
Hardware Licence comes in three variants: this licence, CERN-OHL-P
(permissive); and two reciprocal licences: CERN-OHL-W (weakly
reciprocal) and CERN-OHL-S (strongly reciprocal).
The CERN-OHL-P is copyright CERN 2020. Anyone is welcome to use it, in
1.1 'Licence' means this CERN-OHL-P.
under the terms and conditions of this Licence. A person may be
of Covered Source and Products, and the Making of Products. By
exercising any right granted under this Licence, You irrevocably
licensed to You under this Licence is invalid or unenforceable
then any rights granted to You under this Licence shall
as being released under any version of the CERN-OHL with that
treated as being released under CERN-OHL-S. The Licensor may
